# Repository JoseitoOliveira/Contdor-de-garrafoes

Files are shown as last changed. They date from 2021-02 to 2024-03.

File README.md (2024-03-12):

# Contdor de garrafões
 Contador de garrafoes e controlador de esteira industrial.

## Requisitos:
- Arduino_FreeRTOS.h
- Bounce2.h
- Keypad.h
- LiquidCrystal.h

## Imagens
### 3º layout
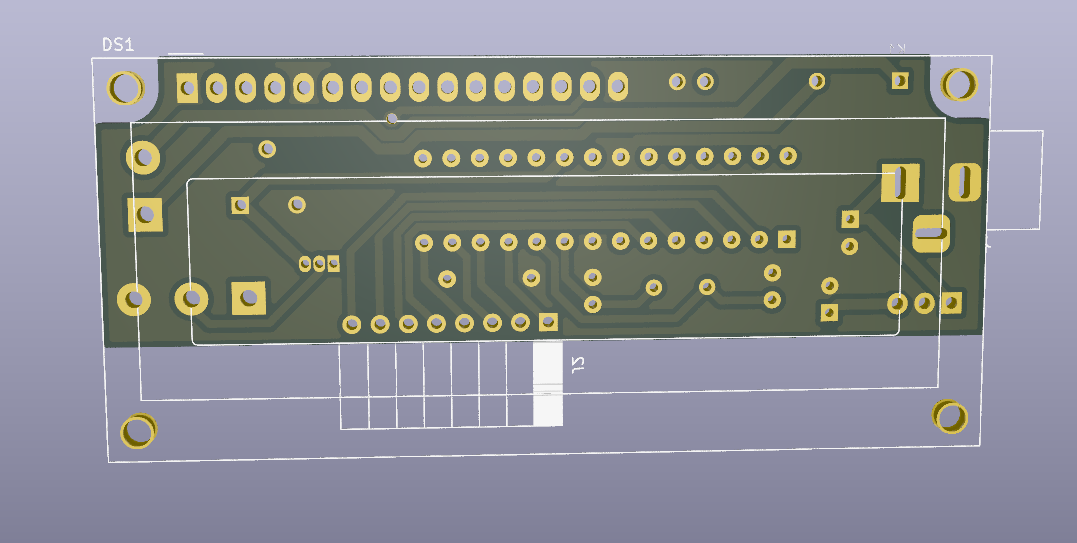
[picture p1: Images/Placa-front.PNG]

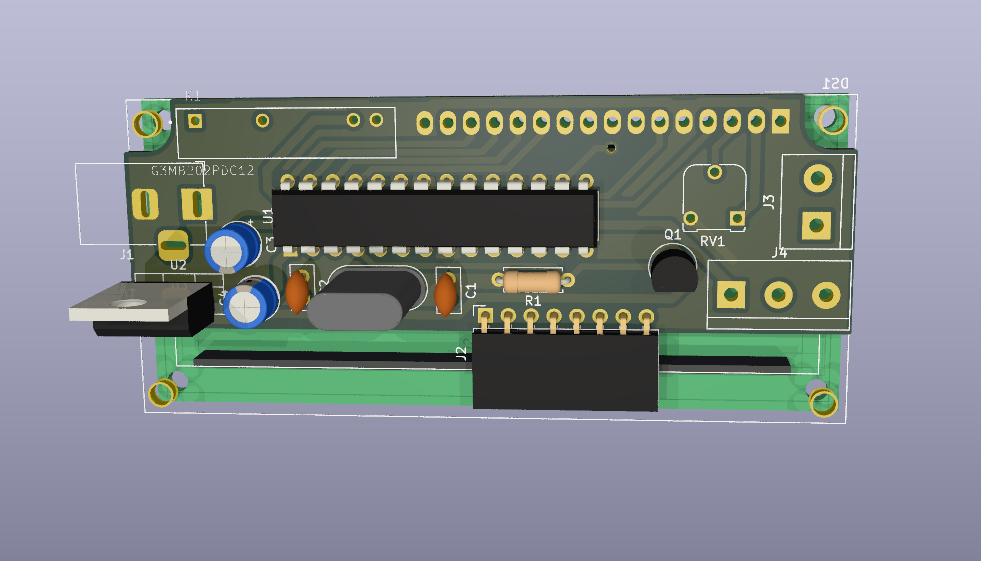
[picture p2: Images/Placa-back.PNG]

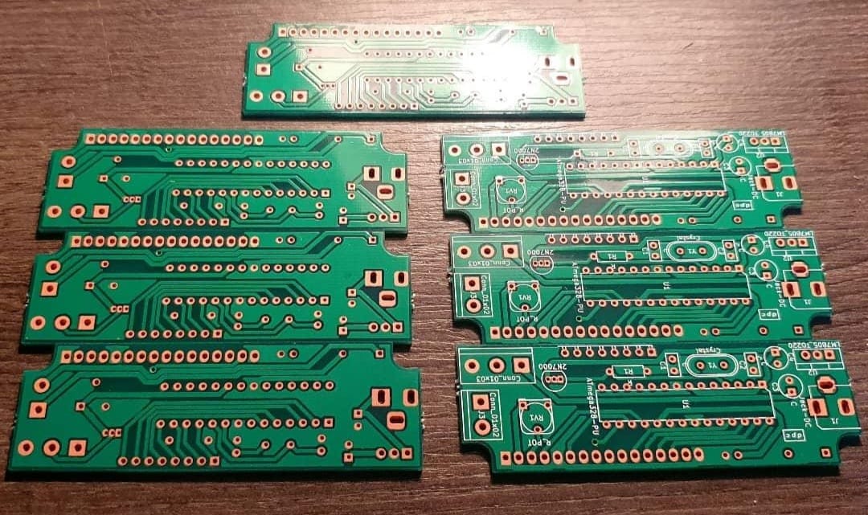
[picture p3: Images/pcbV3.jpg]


### 2º layout
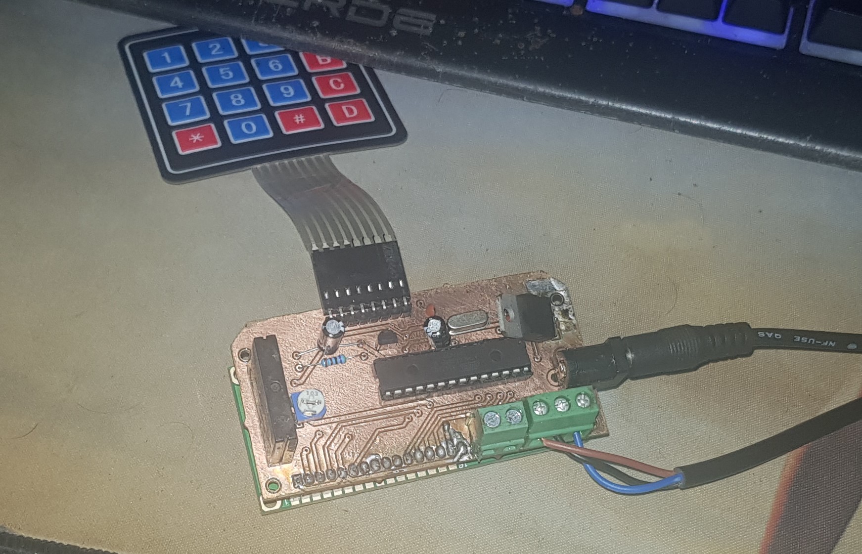
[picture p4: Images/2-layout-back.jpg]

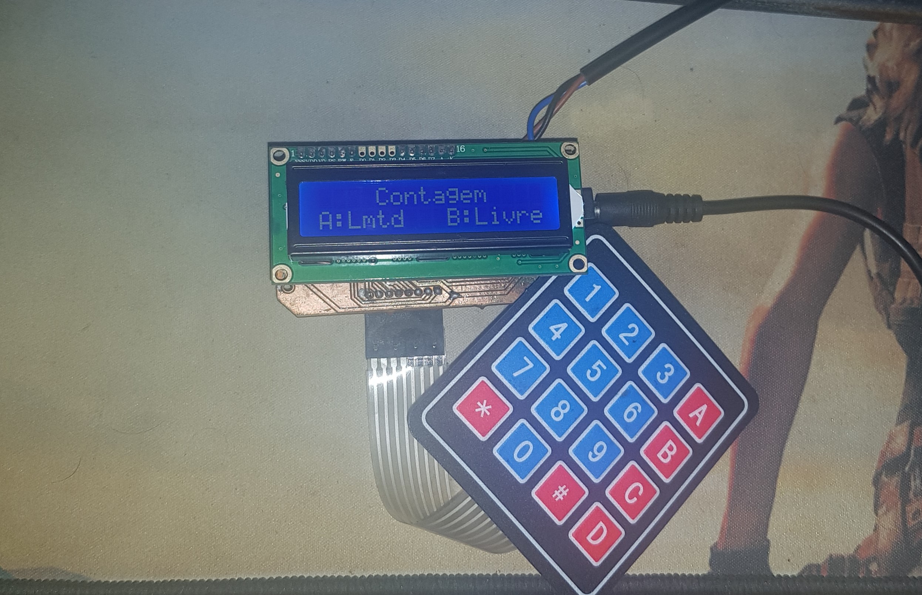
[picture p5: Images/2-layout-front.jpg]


### 1º layout
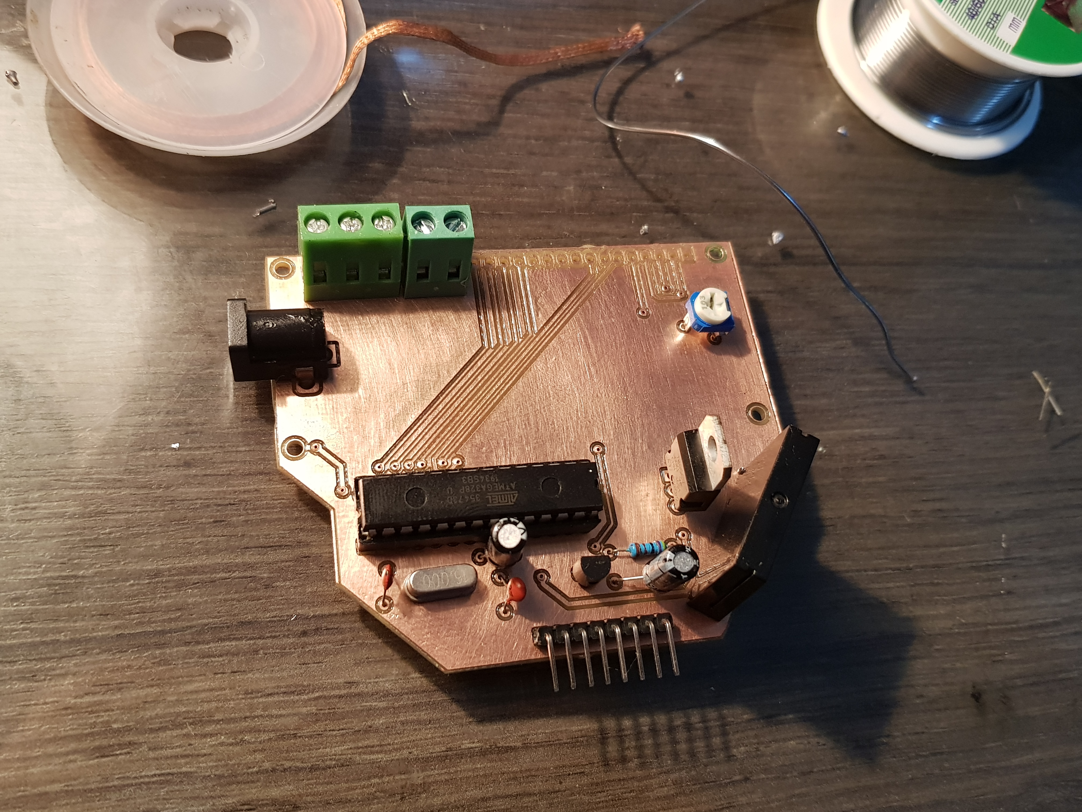
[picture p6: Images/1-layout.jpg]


### 1º montagem em protoboard
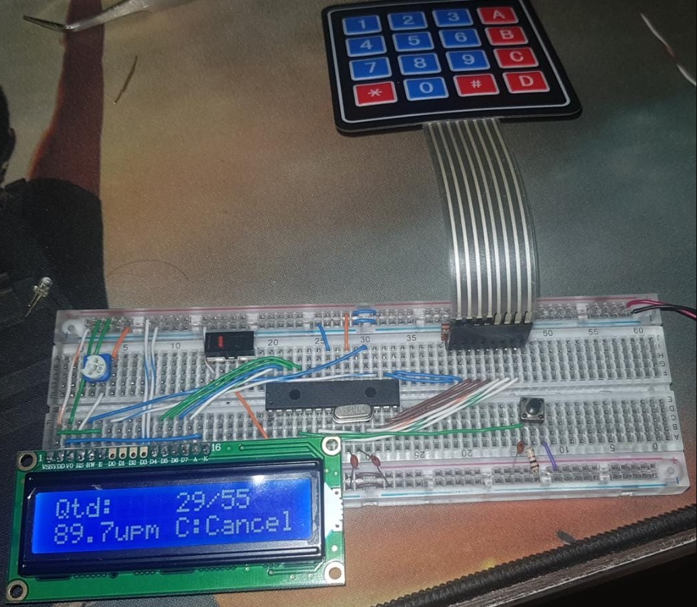
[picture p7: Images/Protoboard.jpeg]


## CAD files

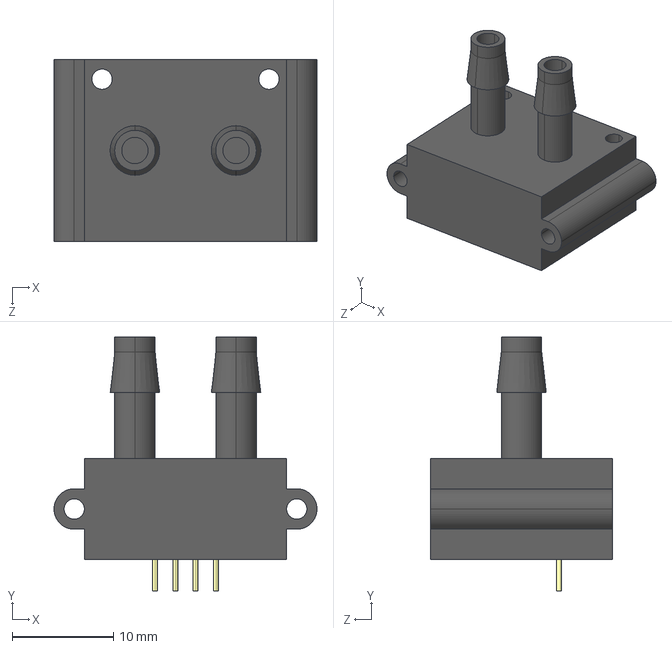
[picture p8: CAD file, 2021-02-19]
Hardware/G3MB202PDC12/G3MB202PDC12.step
26.0 x 25.1 x 18.0 mm

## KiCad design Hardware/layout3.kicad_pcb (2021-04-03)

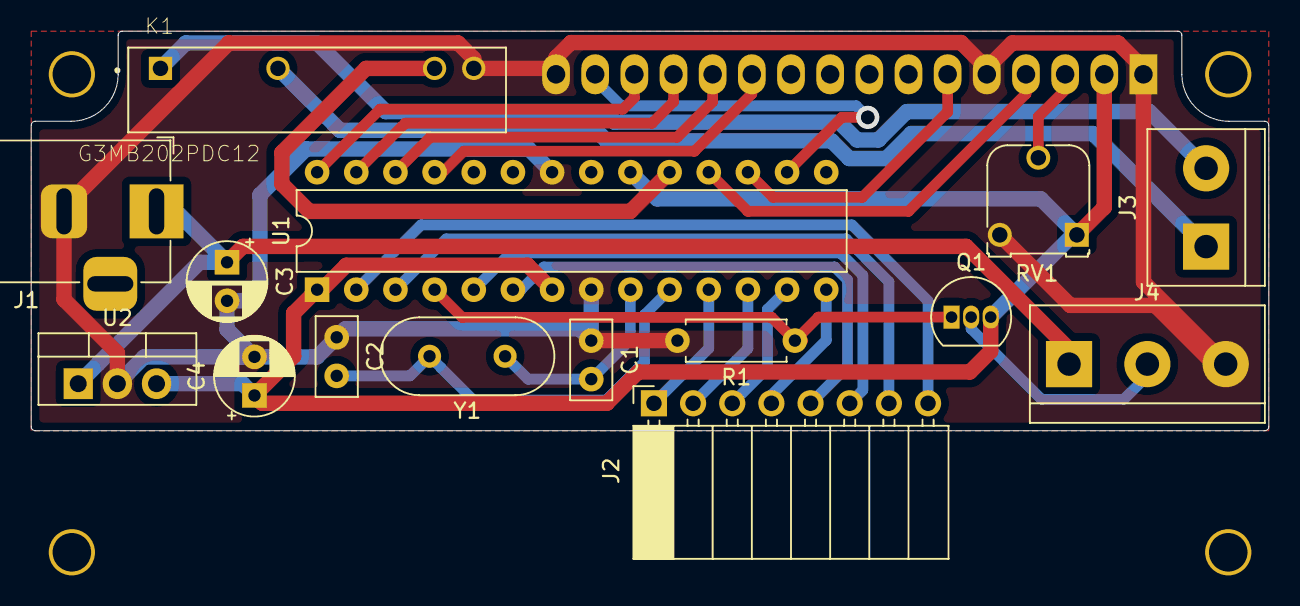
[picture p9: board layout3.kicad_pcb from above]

Board: 2 copper layers, 80.3 x 25.9 mm, 16 parts (1 on the bottom side), 26 nets.

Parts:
C1, C2: C; C_Disc_D5.0mm_W2.5mm_P2.50mm
C3, C4: C; CP_Radial_D5.0mm_P2.50mm
DS1: RC1602A; WC1602A
J1: Jack-DC; BarrelJack_Horizontal
J2: Teclado matricial; PinSocket_1x08_P2.54mm_Horizontal
J3: Conn_01x02; TerminalBlock_bornier-2_P5.08mm
J4: Conn_01x03; TerminalBlock_bornier-3_P5.08mm
K1: G3MB202PDC12; RELAY_G3MB202PDC12
Q1: 2N7000; TO-92_Inline
R1: R; R_Axial_DIN0207_L6.3mm_D2.5mm_P7.62mm_Horizontal
RV1: R_POT; Potentiometer_Runtron_RM-065_Vertical
U1: ATmega328-PU; DIP-28_W7.62mm
U2: LM7805_TO220; TO-220-3_Vertical
Y1: Crystal; Crystal_HC18-U_Vertical

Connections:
GND: C1.1, C2.1, C3.2, C4.2, DS1.1, DS1.5, DS1.16, J1.2, J4.3, K1.4, R1.2, RV1.3, U1.8, U1.22, U2.2
LCD_A: DS1.15, U1.16
unnamed: C1.2, U1.9, Y1.1
unnamed: C2.2, U1.10, Y1.2
unnamed: DS1.3, RV1.2
unnamed: J3.1, K1.2
unnamed: J3.2, K1.1
unnamed: J4.2, Q1.2
Pino_2_int: Q1.1, R1.1, U1.4
Pino_3: J2.8, U1.2
Pino_4: J2.7, U1.3
Pino_5: J2.6, U1.5
Pino_6: J2.5, U1.6
Pino_7: J2.4, U1.14
Pino_8: J2.3, U1.13
Pino_9: J2.2, U1.12
Pino_10: J2.1, U1.11
Pino_11: DS1.6, U1.17
Pino_12: DS1.4, U1.18
Pino_13: K1.3, U1.19
Pino_16_A2: DS1.11, U1.25
Pino_17_A3: DS1.12, U1.26
Pino_18_A4: DS1.13, U1.27
Pino_19_A5: DS1.14, U1.28
vcc: C4.1, DS1.2, Q1.3, RV1.1, U1.1, U1.7, U1.20, U2.3
vcc_12v: C3.1, J1.1, J4.1, U2.1

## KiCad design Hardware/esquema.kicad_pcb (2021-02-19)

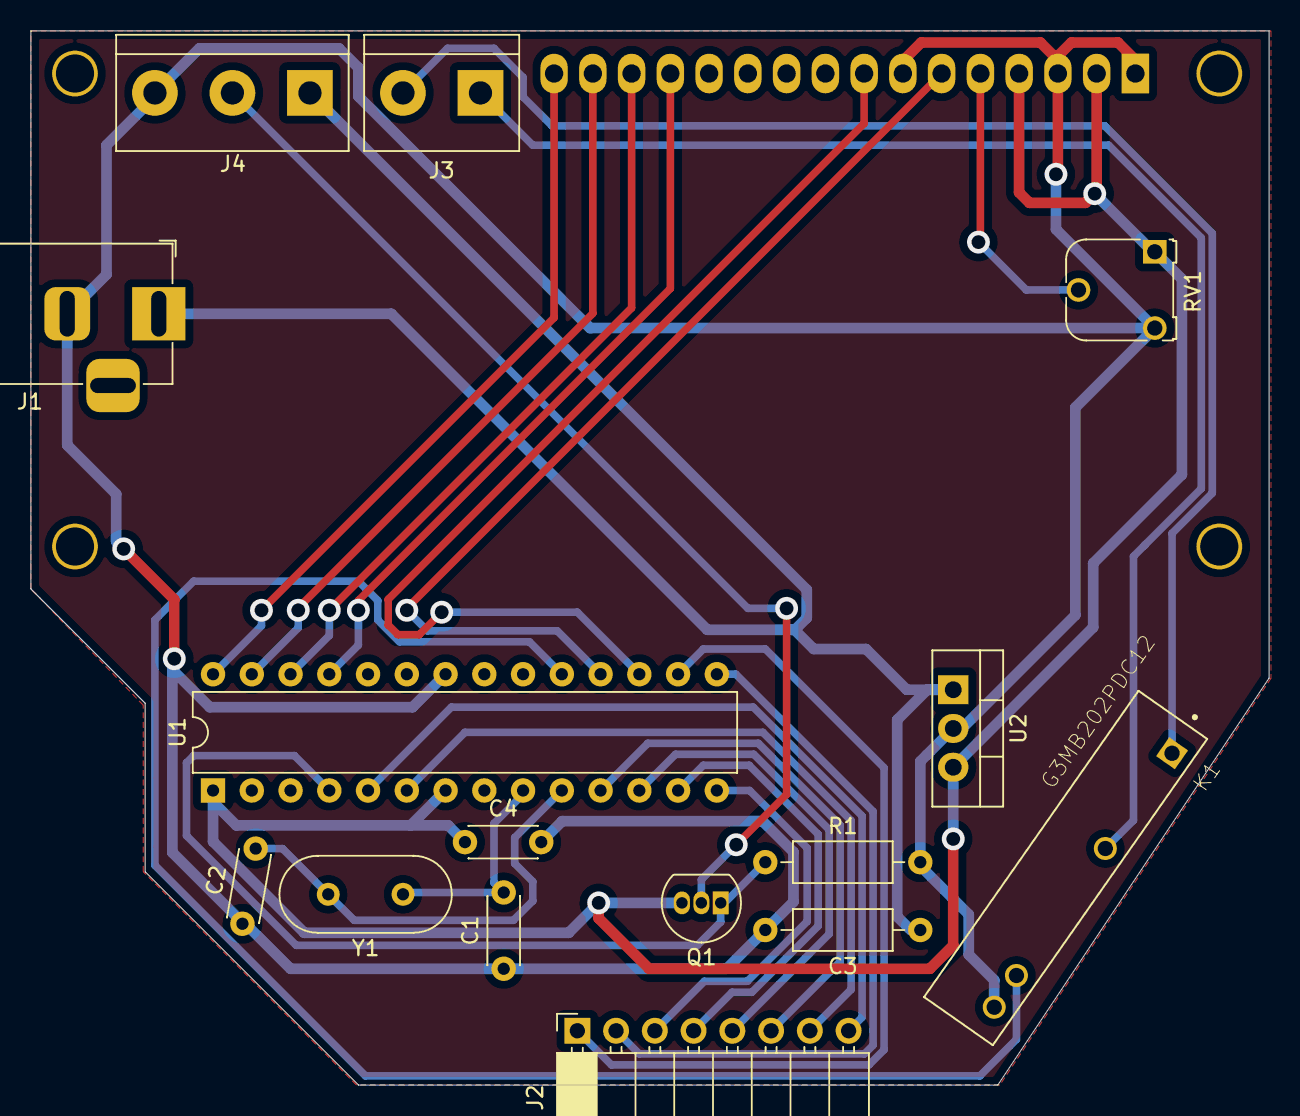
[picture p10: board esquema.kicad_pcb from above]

Board: 2 copper layers, 81.2 x 69.1 mm, 16 parts (1 on the bottom side), 25 nets.

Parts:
C1, C2, C4: C; C_Disc_D4.3mm_W1.9mm_P5.00mm
C3: C; R_Axial_DIN0207_L6.3mm_D2.5mm_P10.16mm_Horizontal
DS1: HY1602E; WC1602A
J1: Jack-DC; BarrelJack_Horizontal
J2: Teclado matricial; PinSocket_1x08_P2.54mm_Horizontal
J3: Conn_01x02; TerminalBlock_bornier-2_P5.08mm
J4: Conn_01x03; TerminalBlock_bornier-3_P5.08mm
K1: G3MB202PDC12; RELAY_G3MB202PDC12
Q1: 2N7000; TO-92_Inline
R1: R; R_Axial_DIN0207_L6.3mm_D2.5mm_P10.16mm_Horizontal
RV1: R_POT; Potentiometer_Runtron_RM-065_Vertical
U1: ATmega328-PU; DIP-28_W7.62mm
U2: LM7805_TO220; TO-220-3_Vertical
Y1: Crystal; Crystal_HC18-U_Vertical

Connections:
GND: C1.1, C2.1, C3.2, C4.2, DS1.1, DS1.3, DS1.7, J1.2, J4.3, K1.4, R1.2, RV1.3, U1.8, U1.22, U2.2
unnamed: C1.2, U1.9, Y1.1
unnamed: C2.2, U1.10, Y1.2
unnamed: DS1.5, RV1.2
unnamed: J3.1, K1.2
unnamed: J3.2, K1.1
unnamed: J4.2, Q1.2
Pino_2_int: Q1.1, R1.1, U1.4
Pino_3: J2.8, U1.5
Pino_4: J2.7, U1.6
Pino_5: J2.6, U1.11
Pino_6: J2.5, U1.12
Pino_7: J2.4, U1.13
Pino_8: J2.3, U1.14
Pino_9: J2.2, U1.15
Pino_10: J2.1, U1.16
Pino_11: DS1.8, U1.17
Pino_12: DS1.6, U1.18
Pino_13: K1.3, U1.19
Pino_16_A2: DS1.13, U1.25
Pino_17_A3: DS1.14, U1.26
Pino_18_A4: DS1.15, U1.27
Pino_19_A5: DS1.16, U1.28
vcc: C4.1, DS1.2, DS1.4, Q1.3, RV1.1, U1.1, U1.7, U1.20, U2.3
vcc_12v: C3.1, J1.1, J4.1, U2.1

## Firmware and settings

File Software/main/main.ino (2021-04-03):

#include <Arduino_FreeRTOS.h>
#include <Bounce2.h>
#include <Keypad.h>
#include <LiquidCrystal.h>

#include "FormatString.hpp"
#include "Numero.hpp"
#include "UnidadesPorMinuto.hpp"
#include "myLCD.hpp"

#define elif else if
#define sensor_pin 2
#define reler_pin 13
#define max_len 5

enum Estados { inicio,
               contagem_limitada,
               contagem_livre,
               digitando
             } estado;

unsigned int max_count;
volatile unsigned int count = 0;
volatile bool sensor_changed = false;

Numero num(max_len);
UnidadePorMinuto upm(10);

// <Teclado>

char matrizteclado[4][4] = {{'1', '2', '3', 'A'},
  {'4', '5', '6', 'B'},
  {'7', '8', '9', 'C'},
  {'*', '0', '#', 'D'}
};

byte pinoslinhas[] = {3, 4, 5, 6};  // pinos utilizados nas linhas
byte pinoscolunas[] = {7, 8, 9, 10};  // pinos utilizados nas colunas

Keypad teclado =
  Keypad(makeKeymap(matrizteclado), pinoslinhas, pinoscolunas, 4, 4);
//</Teclado>

// Protótipos de funções
void func_inicio(char);
void func_contagem_limitada(char);
void func_contagem_livre(char);
void func_digitando(char);

void set_inicio() {
  estado = inicio;
  digitalWrite(reler_pin, LOW);
  count = 0;
  lcd::inicio();
}

void set_digitando() {
  estado = digitando;
  lcd::digitando();
}

void set_contagem_limitada(int max_cout) {
  estado = contagem_limitada;
  digitalWrite(reler_pin, HIGH);
  lcd::contagem_limitada(count, max_cout, 0);
}

void set_contagem_livre() {
  estado = contagem_livre;
  digitalWrite(reler_pin, HIGH);
  lcd::contagem_livre(count, 0);
}

char dialog(String st1, String st2, char opts[]) {
  lcd::dialog(st1, st2);

  while (true) {
    char tecla = teclado.getKey();
    if (tecla) {
      for (byte i = 0; i < sizeof(opts) / sizeof(char); i++) {
        if (opts[i] == tecla) {
          return tecla;
        }
      }
    }
    vTaskDelay(0);
  }
}

void task_tick_sensor(void *_sensor) {

  Bounce * sensor = (Bounce *) _sensor;
  while (true) {
    sensor->update();
    vTaskDelay(10 / portTICK_PERIOD_MS);
  }
}

void task_sensor(void *_sensor) {

  Bounce * sensor = (Bounce *) _sensor;

  while (true) {
    if (estado == contagem_limitada or estado == contagem_livre) {
      if (sensor->changed() and sensor->read() == HIGH) {
        count++;
        upm.tick();
        sensor_changed = true;
      }
    }
    vTaskDelay(30 / portTICK_PERIOD_MS);
  }
}

void task_state(void *pvParameters) {
  (void)pvParameters;

  lcd::begin();

  set_inicio();

  while (true) {
    char tecla = teclado.getKey();

    switch (estado) {
      case inicio:
        func_inicio(tecla);
        break;
      case contagem_limitada:
        func_contagem_limitada(tecla);
        break;
      case contagem_livre:
        func_contagem_livre(tecla);
        break;
      case digitando:
        func_digitando(tecla);
        break;
    }
    vTaskDelay(100 / portTICK_PERIOD_MS);
  }
}

void setup() {
  pinMode(reler_pin, OUTPUT);

  Bounce sensor = Bounce();
  sensor.attach(sensor_pin, INPUT);
  sensor.interval(10);

  TaskHandle_t task_State_Handle;
  TaskHandle_t task_Sensor_Handle;
  TaskHandle_t task_Tick_Sensor_Handle;

  xTaskCreate(
    task_state,
    "State", 255,
    (void *)&sensor,
    5,
    &task_State_Handle
  );

  xTaskCreate(
    task_tick_sensor,
    "Tick Sensor", 50,
    (void *)&sensor,
    10,
    &task_Tick_Sensor_Handle
  );

  xTaskCreate(
    task_sensor,
    "Sensor", 255,
    NULL,
    15,
    &task_Sensor_Handle
  );
}

void loop() {}

void func_inicio(char tecla) {
  switch (tecla) {
    case '1':
    case '2':
    case '3':
    case '4':
    case '5':
    case '6':
    case '7':
    case '8':
    case '9':
    case '0':
      set_digitando();
      num.clear();
      num.add(tecla);
      lcd::display.setCursor(4, 0);
      lcd::display.print(num.ljust());
      break;
    case 'A':
      set_digitando();
      num.clear();
      break;
    case 'B':
      set_contagem_livre();
      break;
  }
}

void func_digitando(char tecla) {
  switch (tecla) {
    case '1':
    case '2':
    case '3':
    case '4':
    case '5':
    case '6':
    case '7':
    case '8':
    case '9':
    case '0':
      num.add(tecla);
      lcd::display.setCursor(4, 0);
      lcd::display.print(num.ljust());
      break;
    case 'D':
      if (num.is_void()) {
        set_inicio();
      } else {
        num.del();
        lcd::display.setCursor(4, 0);
        lcd::display.print(num.ljust());
      }
      break;
    case 'A':
      if (not num.is_void()) {
        set_contagem_limitada(num.toInt());
        max_count = num.toInt();
      }
      break;
    case 'C':
      set_inicio();
      break;
  }
}

void func_contagem_limitada(char tecla) {
  switch (tecla) {
    case 'C':
      char nova_tecla = dialog("Cancel contagem?", "  A:Sim  C:Nao", "AC");
      if (nova_tecla == 'A') {
        set_inicio();
      } else {
        lcd::contagem_limitada(count, max_count, upm.calc());
      }
      break;
  }

  if (sensor_changed) {
    lcd::contagem_limitada(count, max_count, upm.calc());
    sensor_changed = false;
  }
  if (count >= max_count) {
    digitalWrite(reler_pin, LOW);
    char nova_tecla = dialog(
                        "Fim da contagem!",
                        " " + String(count) + "  A:Inicio",
                        "A");
    if (nova_tecla == 'A')
      set_inicio();
  }
}

void func_contagem_livre(char tecla) {
  switch (tecla) {
    case 'C':
      char nova_tecla = dialog("Parar contagem?", "  A:Sim  C:Nao", "AC");
      if (nova_tecla == 'A') {
        set_inicio();
      } else {
        lcd::contagem_livre(count, upm.calc());
      }
      break;
  }

  if (sensor_changed) {
    lcd::contagem_livre(count, upm.calc());
    sensor_changed = false;
  }
}

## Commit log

2021-02-19 Commit Inicial
    [Componentes.xlsx, G3MB202PDC12.step, esquem2.kicad_pcb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]
2021-04-03 Atualização
    [layout2.kicad_pcb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]
